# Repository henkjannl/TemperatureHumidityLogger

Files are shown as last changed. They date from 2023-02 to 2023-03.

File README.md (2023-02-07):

Hoi Jan,

Ik heb een envelop met 3x een BME280 sensor en 3x een ESP32 bordje op je bureau gelegd. Met de BME280 kun je temperatuur, luchtvochtigheid en luchtdruk meten (luchtdruk wist ik niet eens).

Het ESP32 bordje dat ik erbij heb gedaan is van het type "MH-ET Live Minikit". Deze heeft een dubbele rij gaatjes en is daardoor compacter dan de meeste bordjes. In de directory ```01 Electrical``` heb ik een simpel elektrisch schema toegevoegd. Het is niet overal duidelijk gedocumenteerd welke pin bij welk gaatje op het bord hoort (bjvoorbeeld TCK = IO13 etc). Dat heb ik één keer uitgezocht, en toegevoegd op in de Inkscape file (pdf is ook toegevoegd). Om de BME280 op de ESP aan te sluiten heb je maar vier draadjes nodig. Let erop dat je 3V3 als voeding kiest en niet VCC want die is 5 volt en dan blaas je vermoedelijk een ingang op. Controleer steeds goed of je bij de ESP32 het binnenste of het buitenste gaatje kiest.

Verder heb ik in deze directory de file ```ESP cheat sheet.md``` toegevoegd. Hier heb ik onder meer een lijstje van alle I/O's van de ESP32 toegevoegd, en welke je wel en niet kan gebruiken. Dat is ook niet altijd superduidelijk gedocumenteerd en het heeft me in het begin nogal problemen opgeleverd. Er staan ook wat C++ code voorbeeldjes in die ik altijd als geheugensteun gebruik. Het is een markdown file. Misschien moet je een Markdown addon in je browser installeren om deze te bekijken, maar je kunt hem ook in GitHub bekijken (zoals deze ```README.md```).

Ik voeg in de envelop een dun snoertje toe, ik geloof AWG30 o.i.d.. Dit vind ik fijn werken, maar dan is het voor de robuustheid wel fijn om er een huisje omheen te zetten. Ik heb een ontwerp van een behuizing toegevoegd in de directory ```02 Mechanical```. Als WiFi aanstaat kan de ESP32 behoorlijk warm worden. Ik heb daarom de ESP en de sensor ieder een eigen roostertje gegeven, om zoveel mogelijk te voorkomen dat de ESP de sensor opwarmt. Verder heb ik 20 mm afstand tussen de sensor en de ESP gezet, om warmtegeleiding door de behuizing te verminderen. Tenslotte zit er een rib in de 'kabelgoot' om convectie daardoorheen te voorkomen. Je zou er in de software voor kunnen kiezen om de WiFi alleen kort aan te zetten als de sensor een meting gaat doen. Ik heb de FreeCAD file, de STL versie en de STEP versies van de behuizing toegevoegd. Ik heb er één huisje V1 bij gedaan, daarvan is de rand van de afdichting niet zo groot en de deelnaad niet zo handig. Bij het andere huisje (V2) heb ik dit verbeterd.

Ik heb nog niets aan de software gedaan. Ik zou je aanbevelen om het als volgt aan te pakken:
1. BME280 sensor library installeren en testen. De sensorwaarde bijvoorbeeld iedere 10 seconden wegsturen met een ```Serial.printf("Temperature: %.2f Humidity: %.1f \n", bme.readTemperature(), bme.readHumidity(), bme.readPressure() );```. Dit voorbeeldprogramma bewaren zodat je later altijd kunt vergelijken met een werkende versie als het werkelijke programma het niet meer doet (dan weet je bijvoorbeeld zeker dat er niets stuk is).
1. Sensor kalibreren. Als de temperatuursensor niet de juiste temperatuur aangeeft kun je een offset bij de ruwe aarde optellen om de sensor te kalibreren.
1. Waardes naar een database sturen. Hoe je het beste de uitgelezen waarden in een database kunt uploaden is nog wel de vraag. Er zijn enorm veel mogelijkheden. Vaak heb je een account op één of andere webservice nodig die beperkt in functionaliteit en/of ingewikkeld en/of niet altijd gratis is. Lijkt me nu nog niet nodig. Zoek dit dus goed uit voor je eraan begint. Misschien is [Deta Base](https://randomnerdtutorials.com/esp32-deta-base-database-arduino/) een goede optie, maar ik heb er zelf nog geen ervaring mee.
1. Het is leuk om de sensorwaarde via Telegram te kunnen uitlezen. De UniversalTelegram library werkt fijn, maar dan moet je eerst een BotID aanvragen. In [RandomNerdTutorials](https://randomnerdtutorials.com/telegram-group-esp32-esp8266/) staat hoe dat werkt. Kun je van overal ter wereld je sensor uitlezen (maar beter om eerst de sensor uit te lezen via de seriële poort).

HenkJan

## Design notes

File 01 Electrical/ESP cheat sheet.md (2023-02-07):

# ESP cheat sheet

# ESP32 I/O table
https://randomnerdtutorials.com/esp32-pinout-reference-gpios

The pins highlighted in <span style="background-color:lime">green</span> are OK to use. The ones highlighted in <span style="background-color:yellow">yellow</span> are OK to use, but you need to pay attention because they may have unexpected behavior mainly at boot. The pins highlighted in <span style="background-color:#ff6666">red</span> are not recommended to use as inputs or outputs.

Note: all pins in the table below are broken out at the MH-ET LIVE Minikit board

|GPIO | Input | Output | Function  | Notes
|:---:|:---:|:---:|---|---
| 0 | <span style="background-color:yellow"> pulled up</span>  | <span style="background-color:yellow">OK</span> | | outputs PWM signal at boot
| 1 | <span style="background-color:#ff6666"> TX pin </span> | <span style="background-color:yellow">OK</span> | UART0 TXD | debug output at boot
| 2 | <span style="background-color:lime"> OK</span> | <span style="background-color:lime">OK</span> | | connected to on-board LED
| 3 |<span style="background-color:yellow"> OK</span> | <span style="background-color:#ff6666"> RX pin</span> | UART0 RXD | HIGH at boot
| 4 | <span style="background-color:lime"> OK</span> | <span style="background-color:lime"> OK</span> | | 
| 5 | <span style="background-color:lime"> OK</span> | <span style="background-color:lime"> OK</span> | VSPI CS0  | outputs PWM signal at boot
| 6 | <span style="background-color:#ff6666"> x</span> | <span style="background-color:#ff6666"> x</span> | | connected to the integrated SPI flash
| 7 | <span style="background-color:#ff6666"> x</span> | <span style="background-color:#ff6666"> x</span> | | connected to the integrated SPI flash
| 8 | <span style="background-color:#ff6666"> x</span> | <span style="background-color:#ff6666"> x</span> | | connected to the integrated SPI flash
| 9 | <span style="background-color:#ff6666"> x</span> | <span style="background-color:#ff6666"> x</span> | UART1 TXD | connected to the integrated SPI flash
| 10  | <span style="background-color:#ff6666"> x</span> | <span style="background-color:#ff6666"> x</span> | UART1 RXD | connected to the integrated SPI flash
| 11  | <span style="background-color:#ff6666"> x</span> | <span style="background-color:#ff6666"> x</span> | | connected to the integrated SPI flash
| 12  | <span style="background-color:yellow">OK</span> | <span style="background-color:lime">OK</span> | HSPI MISO | boot fail if pulled high
| 13  | <span style="background-color:lime">OK</span> | <span style="background-color:lime">OK</span> | HSPI MOSI |
| 14  | <span style="background-color:lime">OK</span> | <span style="background-color:lime">OK</span> | HSPI CLOCK | outputs PWM signal at boot
| 15  | <span style="background-color:lime">OK</span> | <span style="background-color:lime">OK</span> | HSPI CS0  | outputs PWM signal at boot
| 16  | <span style="background-color:lime">OK</span> | <span style="background-color:lime">OK</span> | |
| 17  | <span style="background-color:lime">OK</span> | <span style="background-color:lime">OK</span> | |
| 18  | <span style="background-color:lime">OK</span> | <span style="background-color:lime">OK</span> | VSPI CLOCK  |
| 19  | <span style="background-color:lime">OK</span> | <span style="background-color:lime">OK</span> | VSPI MISO |
| 21  | <span style="background-color:lime">OK</span> | <span style="background-color:lime">OK</span> | I²C<sub>0</sub> SDA  |
| 22  | <span style="background-color:lime">OK</span> | <span style="background-color:lime">OK</span> | I²C<sub>0</sub> SCL  |
| 23  | <span style="background-color:lime">OK</span> | <span style="background-color:lime">OK</span> | VSPI MOSI |
| 25  | <span style="background-color:lime">OK</span> | <span style="background-color:lime">OK</span> | |
| 26  | <span style="background-color:lime">OK</span> | <span style="background-color:lime">OK</span> | |
| 27  | <span style="background-color:lime">OK</span> | <span style="background-color:lime">OK</span> | |
| 32  | <span style="background-color:lime">OK</span> | <span style="background-color:lime">OK</span> | ADC1/0 |
| 33  | <span style="background-color:lime">OK</span> | <span style="background-color:lime">OK</span> | ADC1/1 |
| 34  | <span style="background-color:lime">OK</span> | | ADC1/2 |  <span style="background-color:yellow">input only</span>
| 35  | <span style="background-color:lime">OK</span> | | ADC1/3 | <span style="background-color:yellow">input only</span>
| 36  | <span style="background-color:lime">OK</span> | | ADC1/4 | <span style="background-color:yellow">input only</span>
| 39  | <span style="background-color:lime">OK</span> | | ADC1/7 | <span style="background-color:yellow">input only</span>
 
# ESP8266 I/O table
https://randomnerdtutorials.com/esp8266-pinout-reference-gpios/

The pins highlighted in <span style="background-color:lime">green</span> are OK to use. The ones highlighted in <span style="background-color:yellow">yellow</span> are OK to use, but you need to pay attention because they may have unexpected behavior mainly at boot. The pins highlighted in <span style="background-color:#ff6666">red</span> are not recommended to use as inputs or outputs.

| PIN | GPIO | Input | Output | Notes
|:---:|:----:|:---:|:---:|---
| D0  | 16 | No interrupt | No PWM or I<sup>2</sup>C support | <span style="background-color:#ff9900"> High at boot</span> <br> Used to wake up from deep sleep
| D1  |  5 | <span style="background-color:lime"> OK</span> | <span style="background-color:lime"> OK </span> | Often used as <span style="background-color:#336699">SCL</span> (I<sup>2</sup>C)
| D2  |  4 | <span style="background-color:lime"> OK</span> | <span style="background-color:lime"> OK </span> | Often used as <span style="background-color:#336699">SDA</span> (I<sup>2</sup>C)
| D3  |  0 | pulled up | <span style="background-color:lime"> OK </span> | Connected to FLASH button<br>Boot fails if pulled LOW
| D4  |  2 | pulled up | <span style="background-color:lime"> OK </span> | <span style="background-color:ff9900ff">HIGH at boot</span><br>Connected to on-board LED<br>Boot fails if pulled LOW
| D5  | 14 | <span style="background-color:lime"> OK</span> | <span style="background-color:lime"> OK</span> | <span style="background-color:#0066cc">SPI</span> SCLK
| D6  | 12 | <span style="background-color:lime"> OK</span> | <span style="background-color:lime"> OK</span> | <span style="background-color:#0066cc">SPI</span> MISO
| D7  | 13 | <span style="background-color:lime"> OK</span> | <span style="background-color:lime"> OK</span> | <span style="background-color:#0066cc">SPI</span> MOSI
| D8  | 15 | Pulled to GND | <span style="background-color:yellow">OK</span> | <span style="background-color:#0066cc">SPI</span> CS <br> Boot fails if pulled HIGH
| RX  |  3 | <span style="background-color:yellow">OK</span> | <span style="background-color:#cc3333">RX pin</span> | <span style="background-color:ff9900">HIGH at boot</span>
| TX  |  1 | <span style="background-color:#cc3333">RX pin</span> | <span style="background-color:yellow">OK</span> | <span style="background-color:ff9900">HIGH at boot</span><br>Debug output at boot<br>Boot fails if pulled LOW
| A0  | ADC0 | <span style="background-color:lime"> Analog<br>input</span> | <span style="background-color:#cc3333"> x</span> |

## Pointers

```c++
char v[6];          // array of 6 characters
char* p = &v[3];    // pointer to one of the characters
char  x = *p;       // *p is the object that p points to
char& c;            // c is a reference to a char in a function call
char* p = nullptr;  // points to nothing, can be compared: there is only one nullptr
const char* commands[] = {"On", "Off", "Timer" }; // array of array of characters
```

## Pointer to a function
```c++
void someFunction(int x) { printf( "%d\n", x ); };
 
int main() {
    void (*pointerToFunction)(int);
    pointerToFunction = &someFunction;
    pointerToFunction(3);
}
```

## Reference
```c++
// Unary suffix & means reference to, we don't need a prefix * to access the value
// this way we ensure the vector v is not copied
void sort(vector<double>& v) { 

// If we are sure we don't want to modify a value, we can use const
void sum(const vector<double>& v) { 
```

## For loop over a container

```c++
const char *colour[] = { "Blue", "Red", "Orange", "Yellow" };
for (auto& c : colour) std::cout << c << "\n";
```

## Struct with list

```c++
enum script_events {displayImage, playSound, closeCurtains, openCurtains, endOfShow};

typedef struct {
  float time;                  // Time the event starts
  enum script_events event;    // Type of event
  char filename[14];           // Filename for image or sound
} type_script;

//Compose the media show, to be extended with enum for sound or filename
static const type_script script[] = {
  {  0.0, displayImage, "/BLK.jpg"},
  {  0.5, openCurtains, ""        },
			:
  { 209.3, endOfShow,     ""       }
};

static const char* const MAIN[] = { "TIMER", "COLOR", "BRIGHTNESS" };

void loop()
{
  timeSec = (float) 0.001 * (millis()-timeOffset);
  // We have not yet come at the end of the show and the time of the next event has arrived
  if ( (script[eventIndex].event != endOfShow) && (timeSec >= script[eventIndex].time) ) {
```

## Creating a list using the standard library
```c++
#include <list>

typedef struct  {
    double x,y;
} tPoint;

int main()
{
	std::list<tPoint> points; 
  points.push_front({0,0});
  points.push_back({1,1});
  firstElement=points.front();
  numElements=points.size();
  
  for (auto const& i : points) {
      std::cout << i.x;
  }  
 ```

## String examples

### Function returning a char* 
```
char* mycharheap(int year)
{
    char* result = new char;
    sprintf(result, "Year: %u",year);
    return result;
}
```

A general form of format specifier is

```
%[flags][width][.precision][length]specifier
```
Given below is a description of each of the parts of format specifier:

| specifier | meaning 
|---|---
| % sign | This is a leading % sign
| flags | They can have the following values:
| | – Left justifies the result within the field. By default, right justified
| | + The sign of the result attached to the beginning of the value including positive results
| | Space  In the absence of a sign, space is attached to the beginning of the result
| | # Specify an alternative form of conversion
| | 0 Used for integer and floating-point numbers. Act as leading zeros in the absence of space.
| Width | Specifies minimum field width in the form of a * or an integer value. This is optional.
| Precision | Specifies precision with a ‘.’ followed by a * or an integer or nothing. This is also optional.
| Length | The optional argument that specified the size of the argument.
| Specifier | This is a conversion format specifier.

Various Format Specifiers used in C++ are as follows:

| Specifier | Description |
|:---:|---|
| % | Prints a % |
| c | Prints single character |
| s | Prints a string | 
| d/i | Converts signed integer to decimal representation |
| o | Converts unsigned integer to octal representation |
| x/X | Converts unsigned integer to hexadecimal representation |
| u | Converts unsigned integer to decimal representation |
| f/F | Converts floating-point number to decimal representation |
| e/E | Converts floating-point number to decimal exponent notation |
|	a/A | Converts floating-point number to a hexadecimal exponent |
|	g/G | Converts floating-point number to decimal or decimal exponent notation  |
|	n | Number of characters written so far by this function call |
|	p | A pointer pointing to Implementation defined character sequence |

### Print to a string

```c++
char data[100];
char* myBlog = "https://arduinobasics.blogspot.com";
int year = 2019;
sprintf(data, "Year: %u, Blog Link: %s",year,myBlog);
```

### Pass string value to function

Alternative 1:
```c++
void drawString(const char *string) {
  ...
}

int main() {
  char text[25];
  sprintf(text, "%02d:%02d:%02d", h,m,s);
  drawString(text);
}
```

Alternative 2:
```c++
void drawString(const String& string)
```

## Class definition

```c++
class Line {
   public:
      Line();  
      void setLength( double len );
      double getLength( void );
  private:
      double length;
};
 
Line::Line(void) {
   cout << "Object is being created" << endl;
}

void Line::setLength( double len ) {
   length = len;
}

double Line::getLength( void ) {
   return length;
}
```

## Main sections of the program

```c++
//====================================================================
//                             Libraries
//====================================================================
#include <FS.h>
#include <math.h>
#include "SPIFFS.h"

//====================================================================
//                             Defines
//====================================================================
#define PI 3.1415926535
```

## Switch case
```c++
switch (script[eventIndex].event) {

  case openCurtains:
	printf("%.3f Open curtains\n", timeSec);
	StepperMove(curtains, timeSec, 3, -CURTAIN_STROKE); 
	break;
}
```

## Short if then else

```c++
x = (val == 10) ? 20 : 15;
```

# Location of Arduino libraries
Way to locate the libraries directory of Arduino is right-clicking the application and choosing ```Open file location``` or ```File``` > ```Preferences``` > ```preferences.txt```
Possible locations:

### Asus:

| Library  | Location
|---|---
| packages | C:\Users\henkj\OneDrive\Documents\Arduino\libraries
| arduino  | C:\Users\henkj\AppData\Local\Arduino15
| esp32 | C:\Users\henkj\AppData\Local\Arduino15\packages\esp32\hardware\esp32\1.0.4\libraries
  
### HP:

| Library | Location
|---|---
| Installed packages  | C:\Users\hjvanderpol\OneDrive\Documents\Arduino\libraries
| ESP native packages | C:\Users\hjvanderpol\AppData\Local\Arduino15\packages
| ESP NOW 8266 | C:\Users\hjvanderpol\AppData\Local\Arduino15\packages\esp8266\hardware\esp8266\2.7.4\tools\sdk\include
| arduino packages | C:\Program Files (x86)\Arduino\libraries

# Bodmer graphics library TFT_eSPI
Modify compilation settings for a specific setup:
 - In ```User_Setup_Select.h``` select if settings need to be retrieved from ```User_Setup.h``` or from one of the predefined configurations such as ```Setup12_M5Stack.h```
 - Potentially mention the screen size when initializing the TFT_eSPI object ```TFT_eSPI tft = TFT_eSPI(320,240);```

For PlatformIO, the library can be found relative to the project directory:

```Project directory\.pio\libdeps\mhetesp32minikit\TFT_eSPI```

Conversion of colors from RGB to 565 can be done by cloning

```C:\Users\henkj\OneDrive\03 HenkJan\14 InternetOfThings\04 ESP32\WashingMachineAlarm\05 User interface\Color converter RGB565.ods```

## Bodmer font sizes:

for(int font=0; font<10; font++)
  Serial.printf("Font %d Width 'XXX' %d Height %d\n" , font, tft.textWidth("XXX", font), tft.fontHeight(font));

| Font  | Width 'XXX' | Height |
|:-----:|:-----------:|:------:|
|    0  |   18 |   0 
|    1  |   18 |   8 
|    2  |   24 |  16 
|    3  |  114 |   0 
|    4  |   45 |  26 
|    5  |  114 |   0 
|    6  |   36 |  48 
|    7  |   36 |  48 
|    8  |   87 |  75 
|    9  |   18 | 107 
|   10  |   18 | 107 
|   11  |   18 | 107 
|   12  |   18 | 107 
|   13  |   18 | 107 
|   14  |   18 | 107 
|   15  |   18 | 239 
|   16  |   18 | 187 
|   17  |   18 |  85 
|   18  |   18 | 107 
|   19  |   18 | 107 

## Create own fonts in Bodmer TFT_eSPI

1. Download processing.ide from https://processing.org/[https://processing.org/]
1. Copy the desired .ttf file to ..\Arduino\libraries\TFT_eSPI\Tools\Create_Smooth_Font\Create_font\data
2. Open ...\Arduino\libraries\TFT_eSPI\Tools\Create_Smooth_Font\Create_font\Create_font.pde with the processing IDE
3. Replace the font filename in line 130: String fontName = "big_noodle_titling";  // Manually crop the filename length later after creation if needed
4. Change the font size if needed in line 137: int  fontSize = 40;
5. Run the program in the Processing IDE
6. Locate the resulting .vlw file in ...\Arduino\libraries\TFT_eSPI\Tools\Create_Smooth_Font\Create_font\FontFiles
7. Convert the .vlw file into a byte string using https://tomeko.net/online_tools/file_to_hex.php?lang=en[https://tomeko.net/online_tools/file_to_hex.php?lang=en]
8. Create a header file in the sketch directory with as first line const uint8_t  YourFontName[] PROGMEM = {
9. Add the bytestring to the header file
10. Add }; after the bytestring
11. In the main sketch, use the font with   tft.loadFont(YourFontName);
Good luck!

# M5 Stack

## M5 Stack library is located in 
C:\Users\hjvanderpol\Documents\Arduino\libraries

## Logging to serial
```c++
Serial.printf("%d > %s\r\n", i, option);
```

# Calling a function with pointers to variables
Function definition:
```c++
void getAcceleration(int16_t* x, int16_t* y, int16_t* z);
```

Variables and function call:
```c++
  int16_t x,y,z;         // raw gyro values

  getAcceleration(&x, &y, &z);
  print(x);
```

# Platform IO

[https://docs.platformio.org/en/latest/platforms/espressif32.html]

## Set monitor baudrate 

In ```platform.ini```:
```
monitor_speed = 115200
```

## Emoticons in Telegram

```c++
const char EMOTICON_BATH[]                = {0xf0, 0x9f, 0x9b, 0x81, 0x0};
const char EMOTICON_BED[]                 = {0xf0, 0x9f, 0x9b, 0x8f, 0x0};
const char EMOTICON_BULLSEYE[]            = {0xf0, 0x9f, 0x8e, 0xaf, 0x0};
const char EMOTICON_CALENDAR[]            = {0xf0, 0x9f, 0x93, 0x85, 0x0};
const char EMOTICON_CAMERA[]              = {0xf0, 0x9f, 0x93, 0xb7, 0x0};
const char EMOTICON_CHECKERED_FLAG[]      = {0xf0, 0x9f, 0x8f, 0x81, 0x0};
const char EMOTICON_CHECKMARK[]           = {0xe2, 0x9c, 0x85, 0x0};
const char EMOTICON_CLOCK[]               = {0xe2, 0x8f, 0xb0, 0x0};
const char EMOTICON_ALARM_CLOCK[]         = {0xe2, 0x8f, 0xb0, 0x0};
const char EMOTICON_CROSSMARK[]           = {0xe2, 0x9d, 0x8c, 0x0};
const char EMOTICON_DOWN_ARROW[]          = {0xe2, 0xac, 0x87, 0xef, 0xb8, 0x8f, 0x0};
const char EMOTICON_FLAME[]               = {0xf0, 0x9f, 0x94, 0xa5, 0x0};
const char EMOTICON_FOOTSTEPS[]           = {0xf0, 0x9f, 0x91, 0xa3, 0x0};
const char EMOTICON_GEAR[]                = {0xe2, 0x9a, 0x99, 0xef, 0xb8, 0x8f, 0x0};
const char EMOTICON_GLASSES[]             = {0xf0, 0x9f, 0x91, 0x93, 0x0};
const char EMOTICON_HAMMER_WRENCH[]       = {0xf0, 0x9f, 0x9b, 0xa0, 0x0};
const char EMOTICON_HOURGLASS[]           = {0xe2, 0x8c, 0x9b, 0xef, 0xb8, 0x8f, 0x0};
const char EMOTICON_HOUSE[]               = {0xf0, 0x9f, 0x8f, 0xa0, 0x0};
const char EMOTICON_ISLAND[]              = {0xf0, 0x9f, 0x8f, 0x96, 0x0};
const char EMOTICON_LAMP[]                = {0xf0, 0x9f, 0x92, 0xa1, 0x0};
const char EMOTICON_MAGIC_STICK[]         = {0xf0, 0x9f, 0xaa, 0x84, 0x0};
const char EMOTICON_OFFICE[]              = {0xf0, 0x9f, 0x8f, 0xa2, 0x0};
const char EMOTICON_PIN[]                 = {0xf0, 0x9f, 0x93, 0x8d, 0x0};
const char EMOTICON_POINTING_FINGER[]     = {0xf0, 0x9f, 0x91, 0x89, 0x0};
const char EMOTICON_RED_QUESTION_MARK[]   = {0xe2, 0x9d, 0x93, 0x0};
const char EMOTICON_RUNNER[]              = {0xf0, 0x9f, 0x8f, 0x83, 0x0};
const char EMOTICON_SHOWER[]              = {0xf0, 0x9f, 0x9a, 0xbf, 0x0};
const char EMOTICON_SMILEY[]              = {0xf0, 0x9f, 0x98, 0x80, 0x0};
const char EMOTICON_STHETOSCOPE[]         = {0xf0, 0x9f, 0xa9, 0xba, 0x0};
const char EMOTICON_STOPWATCH[]           = {0xe2, 0x8f, 0xb1, 0x0};
const char EMOTICON_THERMOMETER[]         = {0xf0, 0x9f, 0x8c, 0xa1, 0x0};
const char EMOTICON_TRIANGLE_DOWN[]       = {0xf0, 0x9f, 0x94, 0xbd, 0x0};
const char EMOTICON_TRIANGLE_UP[]         = {0xf0, 0x9f, 0x94, 0xbc, 0x0};
const char EMOTICON_UP_ARROW[]            = {0xe2, 0xac, 0x86, 0xef, 0xb8, 0x8f, 0x0};
const char EMOTICON_WARNING[]             = {0xe2, 0x9a, 0xa0, 0xef, 0xb8, 0x8f, 0x0};
```

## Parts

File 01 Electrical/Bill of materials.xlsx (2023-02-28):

Quantity | Item | Ordering information
1x | ESP32 MH-ET Live Minikit with CP2104 driver | https://www.aliexpress.com/item/32858054775.html
1x | BME280 3.3V | https://www.aliexpress.com/item/32849462236.html
2x | Black plated Countersunk flat head tapping screw M3x12 | https://www.aliexpress.com/item/4001014535120.html
10 cm | 30AWG wire | https://www.aliexpress.com/item/33030965448.html

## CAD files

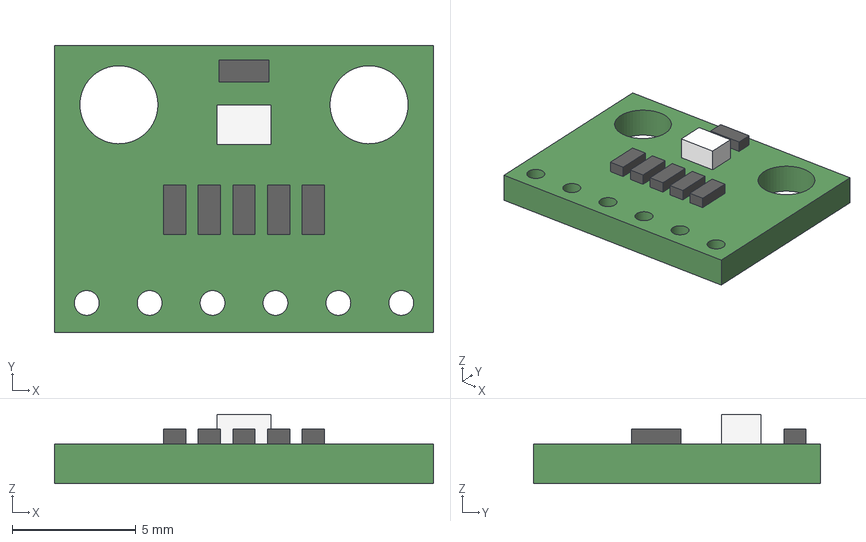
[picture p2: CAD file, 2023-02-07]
02 Mechanical/Components/BMP280 barometer.FCStd
15.3 x 11.6 x 2.80 mm
PCB
BMP280-component
Resistor1
Resistor2
Resistor3
Resistor4
Resistor5
Resistor6

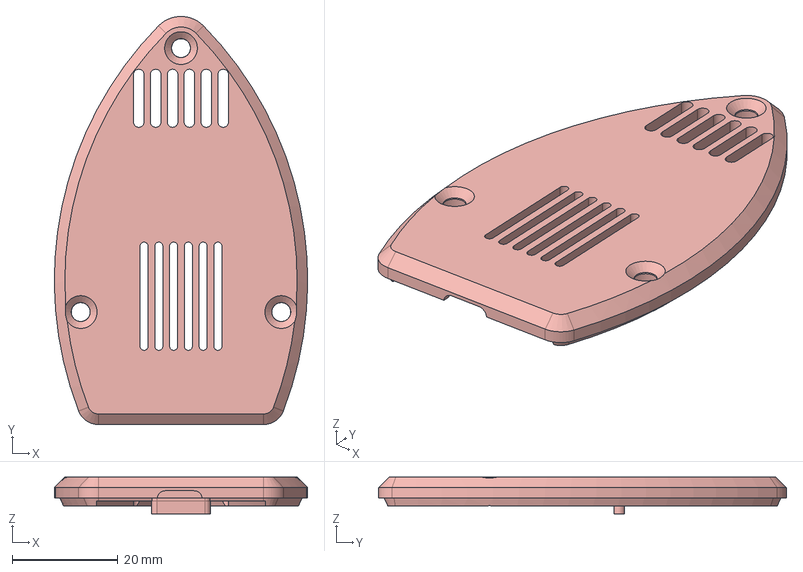
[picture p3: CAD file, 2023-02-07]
02 Mechanical/V1/SensorHousing-Top housing.step
48.0 x 77.3 x 7.00 mm

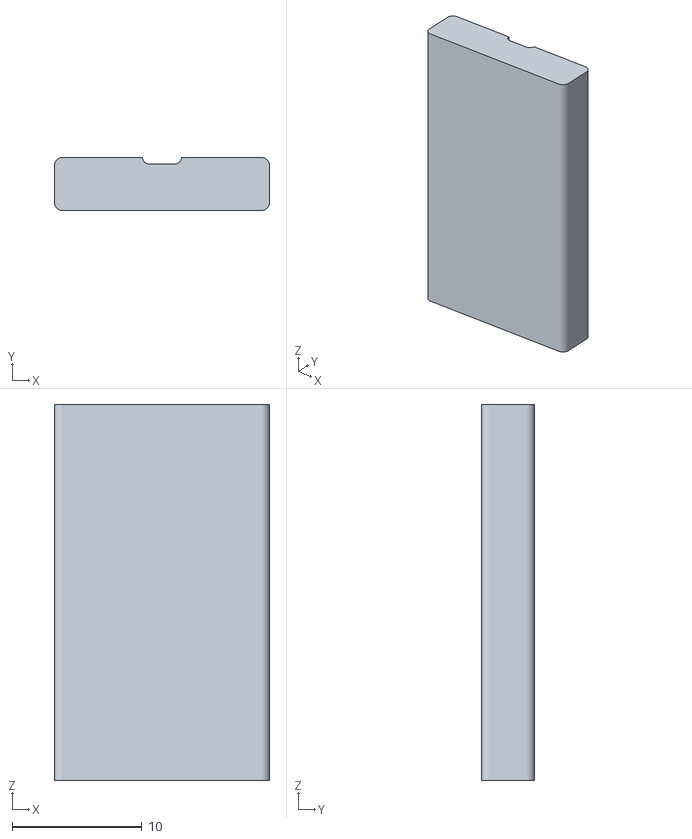
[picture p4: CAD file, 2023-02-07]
02 Mechanical/V3 - vents above separation line/V3spacer.stl
16.6 x 4.10 x 29.0

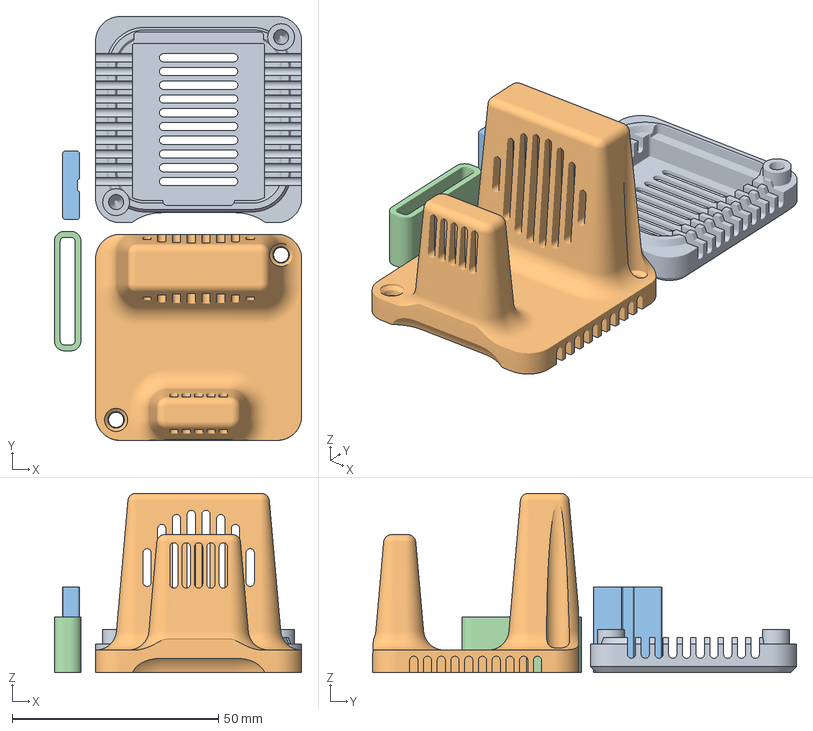
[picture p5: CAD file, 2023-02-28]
02 Mechanical/Version with fan/Version3.3mf
60.0 x 102.8 x 43.5 mm
Bottom housing.stl
Top housing.stl
Sensor spacer.stl
Fan spacer.stl

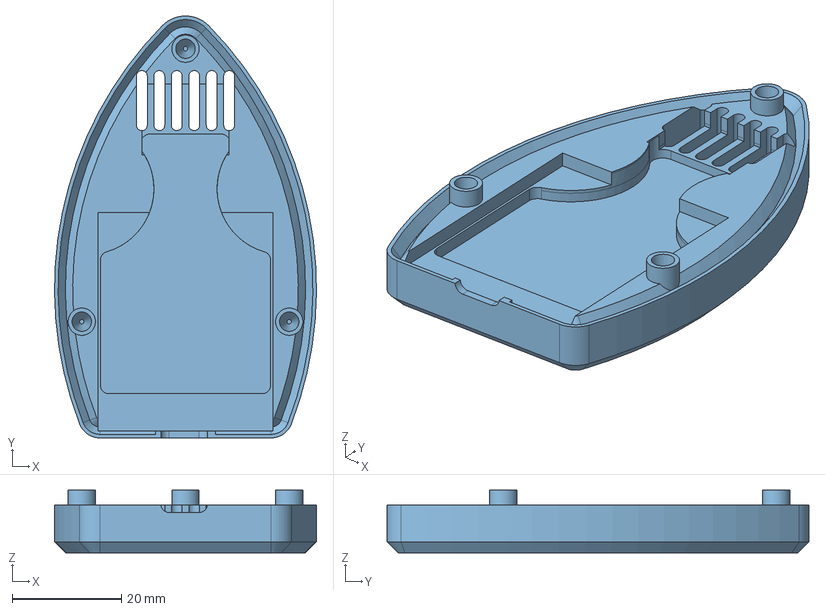
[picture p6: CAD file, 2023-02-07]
02 Mechanical/V1/SensorHousing-Bottom housing.step
48.0 x 77.3 x 11.5 mm

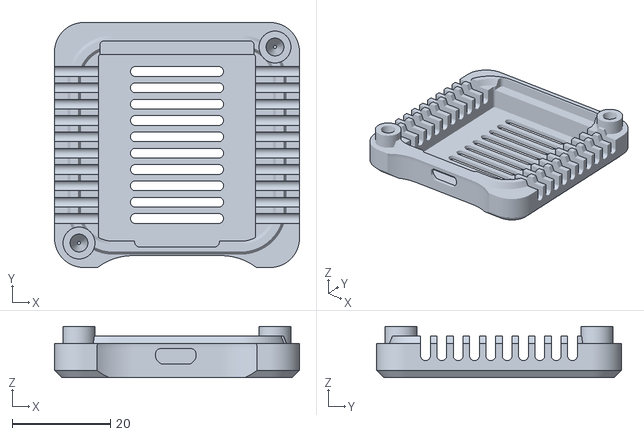
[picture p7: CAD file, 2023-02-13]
02 Mechanical/Version with fan/Bottom housing.stl
50.0 x 50.0 x 10.5

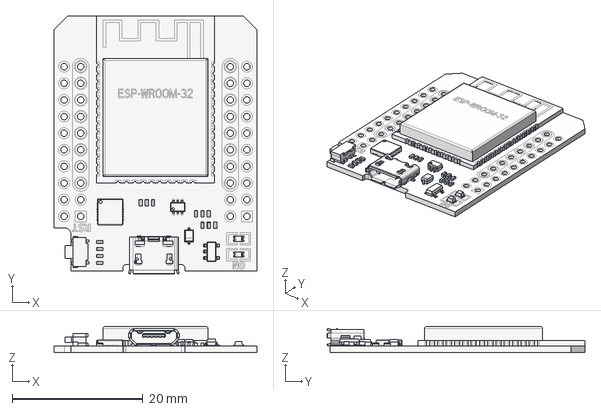
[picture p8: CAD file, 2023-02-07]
02 Mechanical/Components/ESP32-mh-et-live-minikit-d1.FCStd
31.0 x 39.4 x 4.04 mm

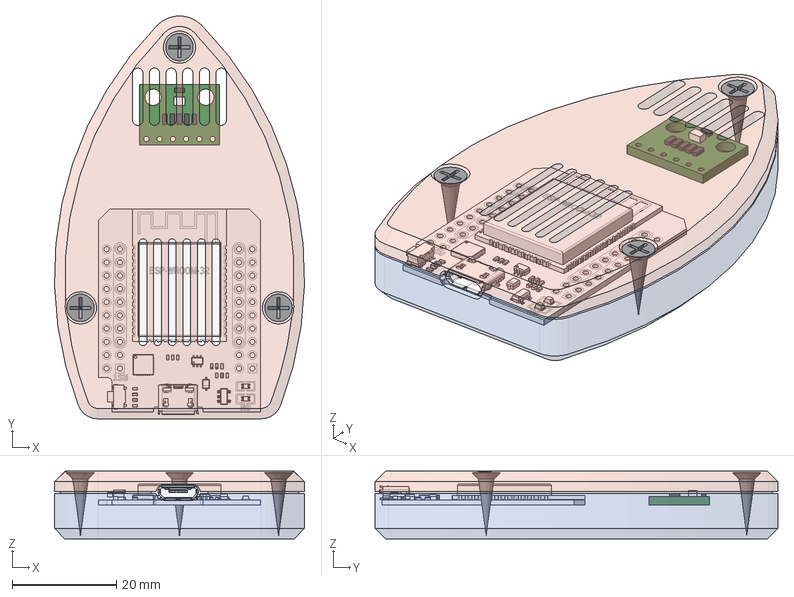
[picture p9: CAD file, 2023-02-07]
02 Mechanical/V1/SensorHousing1.FCStd
48.0 x 77.3 x 13.0 mm
MH-ET_LIVE_MiniKit
PCB
BME280 device
Resistor1
Resistor2
Resistor3
Resistor4
Resistor5
Resistor6
SelftappingScrew3.0x12_01
SelftappingScrew3.0x12_02
SelftappingScrew3.0x12_03
Top housing
Bottom housing

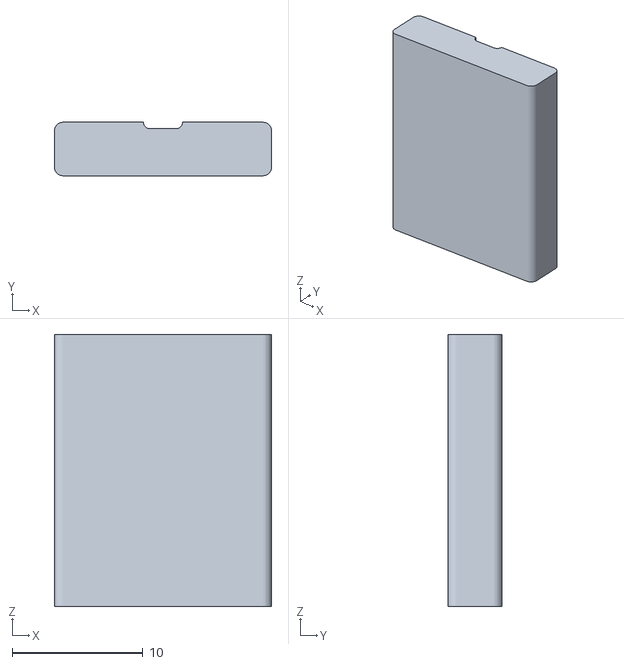
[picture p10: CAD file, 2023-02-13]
02 Mechanical/Version with fan/Sensor spacer.stl
16.6 x 4.10 x 20.8

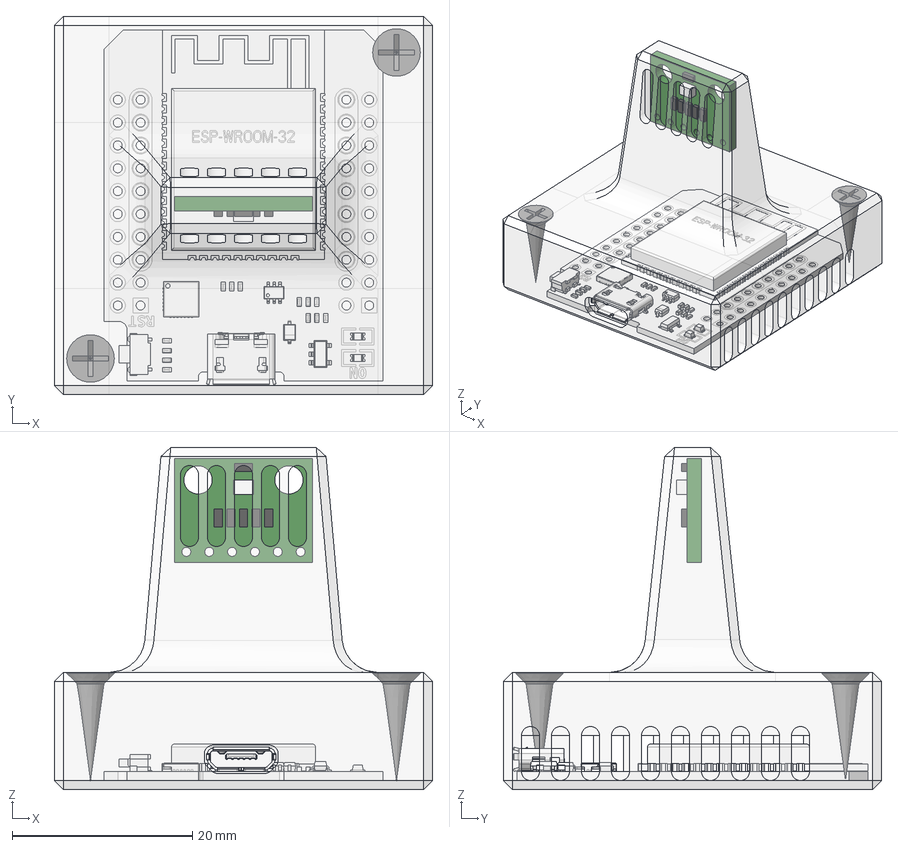
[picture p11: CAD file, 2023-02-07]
02 Mechanical/V1/SensorHousing2.FCStd
42.0 x 42.0 x 38.0 mm
MH-ET_LIVE_MiniKit
PCB
BME280 device
Resistor1
Resistor2
Resistor3
Resistor4
Resistor5
Resistor6
SelftappingScrew3.0x12_01
SelftappingScrew3.0x12_02
Housing

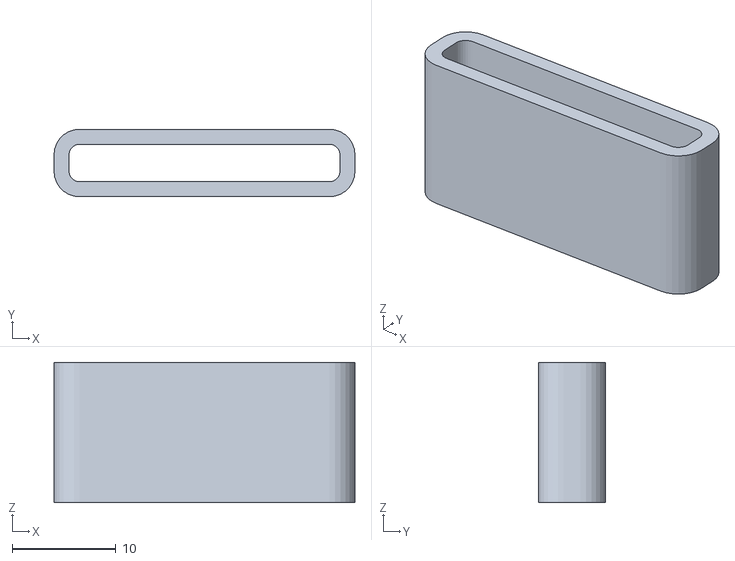
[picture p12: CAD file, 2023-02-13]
02 Mechanical/Version with fan/Fan spacer.stl
29.0 x 6.50 x 13.5

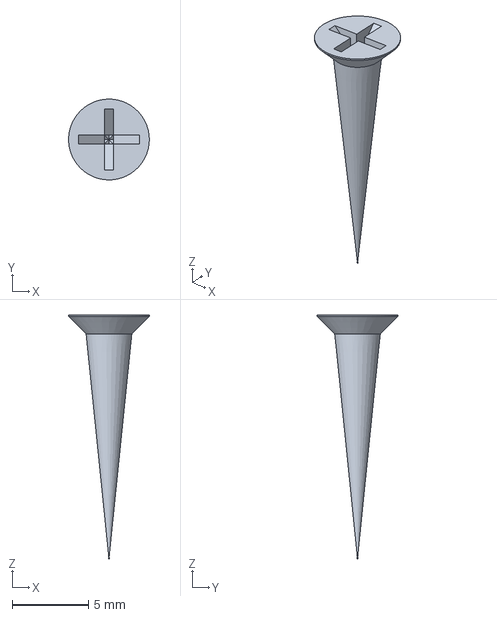
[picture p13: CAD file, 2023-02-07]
02 Mechanical/Components/SelftappingScrew3.0x16.FCStd
5.29 x 5.30 x 16.0 mm

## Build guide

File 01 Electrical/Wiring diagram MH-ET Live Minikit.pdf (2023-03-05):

3V3

GND

SCL

SDA

GPIO
3V3
GND
21
22

Connecon
BMP280
BMP280
BME280 I²C SDA
BME280 I²C SCL

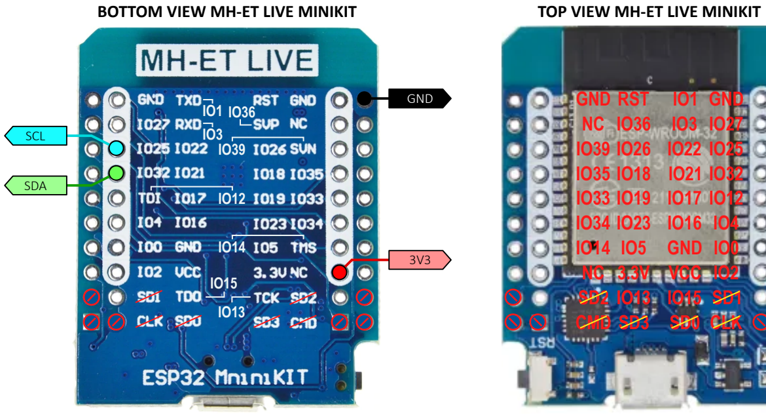
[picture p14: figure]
CMD; CLKSD0SD3; GND RST; GND; IO0GND; NC 3.3V VCC IO2; SCL; SDA; BOTTOM VIEW MH-ET LIVE MINIKIT; TOP VIEW MH-ET LIVE MINIKIT
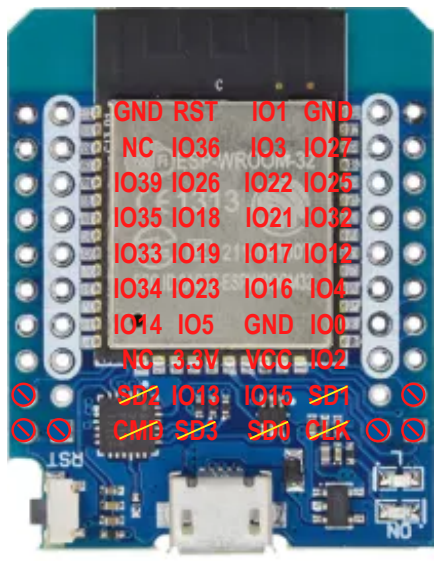
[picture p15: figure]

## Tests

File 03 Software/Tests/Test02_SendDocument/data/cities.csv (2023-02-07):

LatD | "LatM" | "LatS" | "NS" | "LonD" | "LonM" | "LonS" | "EW" | "City" | "State"
41 | 5 | 59 | "N" | 80 | 39 | 0 | "W" | "Youngstown" | OH
42 | 52 | 48 | "N" | 97 | 23 | 23 | "W" | "Yankton" | SD
46 | 35 | 59 | "N" | 120 | 30 | 36 | "W" | "Yakima" | WA
42 | 16 | 12 | "N" | 71 | 48 | 0 | "W" | "Worcester" | MA
43 | 37 | 48 | "N" | 89 | 46 | 11 | "W" | "Wisconsin Dells" | WI
36 | 5 | 59 | "N" | 80 | 15 | 0 | "W" | "Winston-Salem" | NC
49 | 52 | 48 | "N" | 97 | 9 | 0 | "W" | "Winnipeg" | MB
39 | 11 | 23 | "N" | 78 | 9 | 36 | "W" | "Winchester" | VA
34 | 14 | 24 | "N" | 77 | 55 | 11 | "W" | "Wilmington" | NC
39 | 45 | 0 | "N" | 75 | 33 | 0 | "W" | "Wilmington" | DE
48 | 9 | 0 | "N" | 103 | 37 | 12 | "W" | "Williston" | ND
41 | 15 | 0 | "N" | 77 | 0 | 0 | "W" | "Williamsport" | PA
37 | 40 | 48 | "N" | 82 | 16 | 47 | "W" | "Williamson" | WV
33 | 54 | 0 | "N" | 98 | 29 | 23 | "W" | "Wichita Falls" | TX
37 | 41 | 23 | "N" | 97 | 20 | 23 | "W" | "Wichita" | KS
40 | 4 | 11 | "N" | 80 | 43 | 12 | "W" | "Wheeling" | WV
26 | 43 | 11 | "N" | 80 | 3 | 0 | "W" | "West Palm Beach" | FL
47 | 25 | 11 | "N" | 120 | 19 | 11 | "W" | "Wenatchee" | WA
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

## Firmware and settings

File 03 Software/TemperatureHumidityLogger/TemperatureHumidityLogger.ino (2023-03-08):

#include <AsyncTelegram2.h>

// Timezone definition
#include <time.h>
#define MYTZ "CET-1CEST,M3.5.0,M10.5.0/3"

#include <WiFi.h>
#include <WiFiMulti.h>
#include <WiFiClientSecure.h>

#include <Wire.h>
#include <Adafruit_Sensor.h>
#include <Adafruit_BME280.h>

#include "FS.h"
#include "SPIFFS.h"
#include <map>

#define VERSION "1.0.1"

/* 
1.0.0 Initial release
1.0.1 Clear logfile behind OK/Cancel submenu

To do:
- After downloading CSV file, send new keyboard instead of updating previous message
- Structure with sensor data should also include CSV header and line
- Temperature calibration via Telegram
- Also calibrations for other signals?
- Report version if requested under debug button
- Include over the air update via Telegram
*/
 
/*
MyCredentials.h is in gitignore and should have the following content:

const char* token =  "aaaaaaaaaa:bbbbbbbbbbbbbbbbbbbbbbbbbbbbbbbbbbb";  // Telegram token
int64_t userid = 12345678; // User who receives a message after startup

std::map<String, String > ACCESS_POINTS { 
  {"SSID-1", "Password-1" }, 
  {"SSID-2", "Password-2" }, 
  {"SSID-3", "Password-3" } };
*/
#include "MyCredentials.h"

/*
  ELECTRICAL CONNECTIONS
  BME280   ESP32    
  VCC      3V3
  GND      GND
  SCL      IO22
  SDA      IO21
*/
// Messages for he callback functions
#define CB_DOWNLOAD         "cbDownload"
#define CB_CLEAR_LOG_MENU   "cbClearLogMenu" 
#define CB_CLEAR_LOG_OK     "cbClearLogOK" 
#define CB_CLEAR_LOG_CANCEL "cbClearLogCancel" 
#define CB_STATUS           "cbStatus"
#define CB_DEBUG            "cbDebug"

#define LED 2

// Temperature and logging
#define TEMPERATURE_OFFSET -2.1         // Added to raw signal of thermometer
#define LOG_INTERVAL 10                 // Number of minutes between log intervals
#define LOG_FILE "/logfile.csv"         // Name of the logfile

// Emoticons to spice up the Telegram messages
const char EMOTICON_DROPLETS[]    = { 0xf0, 0x9f, 0x92, 0xa6, 0x00 };
const char EMOTICON_TEMPERATURE[] = { 0xf0, 0x9f, 0x8c, 0xa1, 0x00 };
const char EMOTICON_PRESSURE[]    = { 0xf0, 0x9f, 0x8c, 0xaa, 0x00 };
const char EMOTICON_WELCOME[]     = { 0xf0, 0x9f, 0x99, 0x8b, 0xe2, 0x80, 0x8d, 0xe2, 0x99, 0x80, 0xef, 0xb8, 0x8f, 0x00 };

// Structure containing the sensor data
struct sensorData_t {
  public:
    float temperature;
    float pressure;
    float humidity;
  
    void readSensor( Adafruit_BME280 &bme) {
      try {
        temperature = bme.readTemperature() + TEMPERATURE_OFFSET;
        pressure = bme.readPressure();
        humidity = bme.readHumidity();
      } 
      catch (const std::exception& e) {
        Serial.println("Error reading BME280");
        temperature = 999;
        pressure = 999;
        humidity = 999;
      }
    };
};

// Global variables
WiFiMulti wifiMulti;
WiFiClientSecure client;  
AsyncTelegram2 myBot(client);
InlineKeyboard inlineKeyboard, clearLogMenu;
Adafruit_BME280 bme; // I2C
sensorData_t sensorData;

std::map<int, String > dayOfWeek { 
  {0, "SUN" }, 
  {1, "MON" }, 
  {2, "TUE" },
  {3, "WED" }, 
  {4, "THU" }, 
  {5, "FRI" },
  {6, "SAT" } };

void newCSVfile() {
  File file = SPIFFS.open(LOG_FILE, FILE_WRITE);
  if(!file){
      Serial.println("newCSVfile: Failed to open file for writing");
      return;
  }

  char msg[100] = "Date,Time,DateTime,Temperature [°C],Humidity [%],Pressure [hPa],Day of week\n";
  Serial.print(msg);

  if(file.print(msg)){
      Serial.println("New CSV file created");
  } else {
      Serial.println("Create new CSV file unsuccessful");
  }
  file.close();
};

String convertToHexString( String input ) {
  String result = "{ ";
  for( int i=0; i<input.length(); i++ ) {
    result += String("0x") + String( (int) input[i], HEX ) + ", ";
  }
  result+="0x00 };";
  result.toLowerCase();
  Serial.println(input + ": " + result);
  return result;
}

// Callback functions definition for inline keyboard buttons
void onDownload(const TBMessage &queryMsg){
  Serial.println("Sending csv file from filesystem");
  File file = SPIFFS.open(LOG_FILE, "r");
  if (file) {
    myBot.sendDocument(queryMsg, file, file.size(), AsyncTelegram2::DocumentType::CSV, file.name());
    file.close();
  }
  else
    Serial.println("Can't open the file");
  
}

void onClearLogMenu(const TBMessage &queryMsg){
  Serial.println("Pull up clear logfile menu");
  //myBot.endQuery(queryMsg, "New logfile created", false);
  myBot.editMessage(queryMsg.chatId, queryMsg.messageID, "Do you really want to clear the logfile?", clearLogMenu);
}

void onClearLogOK(const TBMessage &queryMsg){
  Serial.println("Clear logfile");
  newCSVfile();
  myBot.editMessage(queryMsg.chatId, queryMsg.messageID, "The logfile was cleared.", inlineKeyboard);
}

void onClearLogCancel(const TBMessage &queryMsg){
  Serial.println("Clear logfile cancelled");
  myBot.editMessage(queryMsg.chatId, queryMsg.messageID, "Clearing of logfile was cancelled.", inlineKeyboard);
}

void onStatus(const TBMessage &queryMsg){
  time_t rawtime;
  struct tm * timeinfo;
  time (&rawtime);
  timeinfo = localtime (&rawtime);
    
  sensorData.readSensor(bme);
  char msg[100];
  snprintf(msg, sizeof(msg), "%02d:%02d %s %.1f°C %s %.1f%% %s %.1f hPa", 
    timeinfo->tm_hour, timeinfo->tm_min, 
    EMOTICON_TEMPERATURE, sensorData.temperature, 
    EMOTICON_DROPLETS, sensorData.humidity, 
    EMOTICON_PRESSURE, sensorData.pressure/100 ); 
  Serial.println(msg);
  
  myBot.editMessage(queryMsg.chatId, queryMsg.messageID, String(msg), inlineKeyboard);
  Serial.println(msg);
}

void onDebug(const TBMessage &queryMsg){
  String msg = String("Version ") + String(VERSION) +"\n" +
               "WiFi connected to" + WiFi.SSID();
  myBot.editMessage(queryMsg.chatId, queryMsg.messageID, msg, inlineKeyboard);
  Serial.println(msg);  
};

void setup() {
  // initialize the Serial
  Serial.begin(115200);
  pinMode(LED, OUTPUT);

  // Start the filesystem 
  Serial.println("Start SPIFFS");
  SPIFFS.begin();  // This will always retain the existing logfile
  // SPIFFS.begin( true ); // This will format SPIFFS for first time use
  
  // Start the BME280 temperature humidity pressure sensor
  Serial.println("Start BME280");
  try {
    bme.begin(0x76);   
  } catch (const std::exception& e) {
    Serial.println("Error initializing BME280");
  }

  Serial.println("Start wifi");
  WiFi.mode(WIFI_STA);

  // Add wifi access points 
  for (const auto &ap : ACCESS_POINTS ) {
    Serial.printf( "%s\n", ap.first.c_str() );
    wifiMulti.addAP( ap.first.c_str(), ap.second.c_str() );
  }

  Serial.println("Connecting Wifi...");
  if(wifiMulti.run() == WL_CONNECTED) {
    Serial.println("WiFi connected");
    Serial.println("IP address: ");
    Serial.println(WiFi.localIP());
  }
  else {
    Serial.println("WiFi not connected yet");
  }

  WiFi.setAutoReconnect(true);

  // Sync time with NTP
  Serial.println("Sync with timeserver");
  configTzTime(MYTZ, "time.google.com", "time.windows.com", "pool.ntp.org");
  client.setCACert(telegram_cert);

  // Set the Telegram bot properties
  Serial.println("Start Telegram");
  myBot.setUpdateTime(1000);
  myBot.setTelegramToken(token);
  myBot.setMyCommands("/start", "start conversation");

  // Check if all things are ok
  Serial.print("Test Telegram connection... ");
  myBot.begin() ? Serial.println("OK") : Serial.println("NOK");
  Serial.print("Bot name: @");
  Serial.println(myBot.getBotName());

  // Add sample inline keyboard
  inlineKeyboard.addButton("Download logfile",  CB_DOWNLOAD,       KeyboardButtonQuery, onDownload);
  inlineKeyboard.addButton("Clear logfile",     CB_CLEAR_LOG_MENU, KeyboardButtonQuery, onClearLogMenu);
  // add a new empty button row
  inlineKeyboard.addRow();
  inlineKeyboard.addButton("Update status",     CB_STATUS,         KeyboardButtonQuery, onStatus);
  inlineKeyboard.addRow();
  inlineKeyboard.addButton("Debug",             CB_DEBUG,          KeyboardButtonQuery, onDebug);
    
  // Add OK cancel menu 
  clearLogMenu.addButton("Cancel",  CB_CLEAR_LOG_CANCEL, KeyboardButtonQuery, onClearLogCancel);
  clearLogMenu.addButton("OK",      CB_CLEAR_LOG_OK,     KeyboardButtonQuery, onClearLogOK);

  // Add pointer to this keyboard to bot (in order to run callback function)
  myBot.addInlineKeyboard(&inlineKeyboard);
  myBot.addInlineKeyboard(&clearLogMenu);

  Serial.println("Start SPIFFS");
  String text = String(EMOTICON_WELCOME) + " Welcome!";
  myBot.sendTo(userid, text.c_str(), inlineKeyboard.getJSON() );
}


void loop() {
  time_t rawtime;
  struct tm * timeinfo;
  static int prev_min = -1;
  static bool wificonnectReported = false;

  // Reconnect wifi if required
  if(wifiMulti.run() != WL_CONNECTED) {
    if (!wificonnectReported) {
      Serial.println("WiFi not connected!");
      wificonnectReported=true;
    } 
  } 
  else {
    wificonnectReported=false;
  }

  // Add a new line to the csv file every 10 minutes
  time (&rawtime);
  timeinfo = localtime (&rawtime);
  if( ( timeinfo->tm_year > 80 ) and ( timeinfo->tm_min != prev_min ) and ( timeinfo->tm_min % LOG_INTERVAL == 0 ) ) {
    prev_min = timeinfo->tm_min;
    digitalWrite(LED, HIGH);   
    char msg[200];
    sensorData.readSensor(bme);
    snprintf( msg, sizeof(msg), "%04d-%02d-%02d,%02d:%02d,%04d-%02d-%02d %02d:%02d,%.3f,%.3f,%.3f,%s\n", 
       1900 + timeinfo->tm_year, timeinfo->tm_mon + 1, timeinfo->tm_mday,                                        // Just the date
       timeinfo->tm_hour, timeinfo->tm_min,                                                                      // Just the time
       1900 + timeinfo->tm_year, timeinfo->tm_mon + 1, timeinfo->tm_mday, timeinfo->tm_hour, timeinfo->tm_min,   // Date and time
       sensorData.temperature,                                                                                   // Temperature
       sensorData.humidity,                                                                                      // Humidity
       sensorData.pressure/100,                                                                                  // Pressure
       dayOfWeek[ timeinfo->tm_wday ] );                                                                         // Day of week

    Serial.println("Append to CSV file");
    Serial.println(msg);

    File file = SPIFFS.open(LOG_FILE, FILE_APPEND);
    if(!file){
        Serial.println("Failed to open CSV for appending");
        newCSVfile();
        File file = SPIFFS.open(LOG_FILE, FILE_APPEND);
    }
    if(file.print(msg)){
        Serial.println("Message appended to CSV file");
    } else {
        Serial.println("Append to CSV file failed");
    }
    file.close();    
    delay(500);                      
    digitalWrite(LED, LOW);
  }
  
  // a variable to store telegram message data
  TBMessage msg;

  // if there is an incoming message...
  if (myBot.getNewMessage(msg)) {
    // check what kind of message I received
    String tgReply;
    MessageType msgType = msg.messageType;
    
    switch (msgType) {
      case MessageText :
        // received a text message
        tgReply = msg.text;
        Serial.print("Text message received: ");
        Serial.println(tgReply);

        if (tgReply.equalsIgnoreCase("/start")) {          
          myBot.sendMessage(msg, "Welcome!", inlineKeyboard);          
        }        
        else {
          // write back feedback message and show a hint
          String text = String("const char EMOTICON[] = ") + convertToHexString( msg.text );
          myBot.sendMessage(msg, text.c_str(), inlineKeyboard);


          
        }
        break;
        
        /* 
        * Telegram "inline keyboard" provide a callback_data field that can be used to fire a callback fucntion
        * associated at every inline keyboard buttons press event and everything can be handled in it's own callback function. 
        * Anyway, is still possible poll the messagetype in the same way as "reply keyboard" or both.              
        */
        case MessageQuery:
          break;
        
        default:
          break;
    }
  }
}

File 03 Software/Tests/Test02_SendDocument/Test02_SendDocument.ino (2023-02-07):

#include <WiFiClientSecure.h>
#include <AsyncTelegram2.h>
#include <map>
#include <Wire.h>
#include <SPI.h>
#include <Adafruit_Sensor.h>
#include <Adafruit_BME280.h>
#include "FS.h"
#include "SPIFFS.h"

#include "MyCredentials.h"
/* The second file in the same folder as this sketch named "MyCredentials.h" contains:
const char* ssid  =  "xxxxxxxxx";     // SSID WiFi network
const char* pass  =  "xxxxxxxxx";     // Password  WiFi network
const char* token =  "xxxxxx:xxxxxxxxxxxxx";  // Telegram token

int64_t userid = 123456789;

I included MyCredentials.h to prevent the information from being uploaded to github (MyCredentials.h is in gitignore)
*/

// Timezone definition
#define MYTZ "CET-1CEST,M3.5.0,M10.5.0/3"

#define FORMAT_SPIFFS_IF_FAILED false
#define LOG_FILE "/templog.csv"
#define SEND_LOG_CALLBACK  "sendlog"
#define STATUS_CALLBACK    "status"
#define CLEAR_LOG_CALLBACK "clearlog"
#define SENSOR_OFFSET -6.6 // 18.1-24.7


// The secure wifi client
WiFiClientSecure client;
#ifdef ESP8266
#include <ESP8266WiFi.h>
  Session   session;
  X509List  certificate(telegram_cert);
#endif

// The Telegram bot
AsyncTelegram2 myBot(client);
InlineKeyboard inlineKeyboard; 

Adafruit_BME280 bme; // I2C

// Logdata, with times and measured temperatures
std::map<time_t, float> TemperatureLog;

// Callback functions definition for inline keyboard buttons
void onSendLog(const TBMessage &queryMsg){
  // Write logdata to CSV file
  Serial.println("\nCreating csv file");
  File file = SPIFFS.open(LOG_FILE, FILE_WRITE);
  file.print("\"Time\",\"Temperature\"\n");
  
  struct tm * localTime;
  for (auto const& datapoint : TemperatureLog) {
      localTime = localtime(& (datapoint.first) );
      file.printf("%04d-%02d-%02d %02d:%02d:%02d,%.6f\n", 
        localTime->tm_year+1900, localTime->tm_mon+1, localTime->tm_mday,
        localTime->tm_hour, localTime->tm_min, localTime->tm_sec, 
        datapoint.second ); 
  }
  
  file.close();
  
  Serial.println("\nSending csv file");
  file = SPIFFS.open(LOG_FILE, "r");
  if (file) {
    myBot.sendDocument(queryMsg, file, file.size(), AsyncTelegram2::DocumentType::CSV, file.name());
    file.close();
    myBot.sendMessage(queryMsg, "Log file sent", inlineKeyboard);          
  }
  else
    Serial.println("Can't open the file. Upload \"data\" folder to filesystem");
};

void onStatus(const TBMessage &queryMsg){
  float tempC = 3.0+SENSOR_OFFSET;
  String message = "Current temperature " + String(tempC, 3) + "°C";
  myBot.editMessage(queryMsg, message.c_str(), inlineKeyboard);    
}

void onClearLog(const TBMessage &queryMsg){
  TemperatureLog.clear();
  Serial.println("Logfile cleared");
  myBot.editMessage(queryMsg, "Log file cleared", inlineKeyboard);          
}

// General setup function
void setup() {
  // initialize the Serial
  Serial.begin(115200);

  bme.begin(0x76);   

  WiFi.setAutoConnect(true);
  WiFi.mode(WIFI_STA);

  // connects to access point
  WiFi.begin(ssid, pass);
  while (WiFi.status() != WL_CONNECTED) {
    Serial.print('.');
    delay(500);
  }
  Serial.println("\nWiFi connected");
  Serial.println(WiFi.localIP());

  if(!SPIFFS.begin(FORMAT_SPIFFS_IF_FAILED)){
      Serial.println("SPIFFS Mount Failed");
      return;
  }

  listDir("/", 0);
  

  // Sync time with NTP
  configTzTime(MYTZ, "time.google.com", "time.windows.com", "pool.ntp.org");
  client.setCACert(telegram_cert);

  // Add inline keyboard
  inlineKeyboard.addButton("Send logfile",  SEND_LOG_CALLBACK,  KeyboardButtonQuery, onSendLog);
  inlineKeyboard.addButton("Clear logfile", CLEAR_LOG_CALLBACK, KeyboardButtonQuery, onClearLog);
  inlineKeyboard.addRow();
  inlineKeyboard.addButton("Update status", STATUS_CALLBACK,    KeyboardButtonQuery, onStatus);

  // Set the Telegram bot properies
  myBot.setUpdateTime(1000);
  myBot.setTelegramToken(token);

  // Check if all things are ok
  Serial.print("\nTest Telegram connection... ");
  myBot.begin() ? Serial.println("OK") : Serial.println("NOK");
  myBot.addInlineKeyboard(&inlineKeyboard);

  myBot.setFormattingStyle(AsyncTelegram2::FormatStyle::HTML /* MARKDOWN */);

  // Send a welcome message to user when ready
  char welcome_msg[128];
  snprintf(welcome_msg, sizeof(welcome_msg),
          "BOT @%s online.\n/help for command list.",
          myBot.getBotName());

  myBot.sendTo(userid, welcome_msg);
}

// General loop function
void loop() {
  printHeapStats();

  static uint32_t lastMeasurement = 0;
  static uint32_t logInterval = 1000*3;
  if ( millis() - lastMeasurement > logInterval ) {
    lastMeasurement = millis();
    time_t now;
    time(&now); // Get current time
    float tempC = 3.0+SENSOR_OFFSET;
    TemperatureLog[now]=tempC;
    Serial.printf("Temperature: %.3f°C\n", tempC);
    if( TemperatureLog.size()>10 ) logInterval = 1000*60*3; // Go to lower frequency after some samples, for debugging.
  }

  // a variable to store telegram message data
  TBMessage msg;

  // if there is an incoming message...
  if (myBot.getNewMessage(msg)) {
    Serial.printf("Message from chatID: %d", msg.chatId);
    MessageType msgType = msg.messageType;

    // Received a text message
    if (msgType == MessageText){
      String msgText = msg.text;
      Serial.print("Text message received: ");
      Serial.println(msgText);

      // Send a csv file passing the stream
      if (msgText.indexOf("/log") > -1) onSendLog(msg);
        
      else if (msgText.indexOf("/clear") > -1) onClearLog(msg);

      else {
        myBot.sendMessage(msg, "Welcome to the temperature logger\nchoose a button", inlineKeyboard);
      }
    }
  }
}

// List all files saved in the selected filesystem
void listDir(const char * dirname, uint8_t levels) {
  Serial.printf("Listing directory: %s\r\n", dirname);
  File root = SPIFFS.open(dirname, "r");
  if (!root) {
    Serial.println("- failed to open directory\n");
    return;
  }
  if (!root.isDirectory()) {
    Serial.println(" - not a directory\n");
    return;
  }
  File file = root.openNextFile();
  while (file) {
    if (file.isDirectory()) {
      Serial.printf("  DIR : %s\n", file.name());
      if (levels)
        listDir(file.name(), levels - 1);
    }
    else
      Serial.printf("  FILE: %s\tSIZE: %d\n", file.name(), file.size());
    file = root.openNextFile();
  }
}

void printValues() {
    Serial.print("Temperature = ");
    Serial.print(bme.readTemperature());
    Serial.println(" °C");

    Serial.print("Pressure = ");

    Serial.print(bme.readPressure() / 100.0F);
    Serial.println(" hPa");

    Serial.print("Humidity = ");
    Serial.print(bme.readHumidity());
    Serial.println(" %");

    Serial.println();
}
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

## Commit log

2023-02-07 Wiring completed
    [BMP280 barometer.FCStd, ESP32-mh-et-live-minikit-d1.FCStd, SelftappingScrew3.0x16.FCStd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]
2023-02-08 First working version 1.0.0
    [logfile.csv]
2023-02-13 Version with fan added
    [20230213 Logfile.xlsx, Bottom housing.stl, Fan spacer.stl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]
2023-02-28 BOM added
    [Bill of materials.xlsx, Bottom housing.stl, Fan spacer.stl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]
2023-03-05 Error in electrical pdf solved, V3 easier to print
    [V3spacer.stl]
2023-03-05 Number on housing added
